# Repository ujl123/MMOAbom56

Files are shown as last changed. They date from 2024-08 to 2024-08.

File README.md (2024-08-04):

# MMOAbom56
WIP board for the MMOAbom56, a board ostensibly for playing mmo games.
The board technically works as-is, but build at your own risk and all that.

Followed the guide on https://flatfootfox.com/ergogen-introduction/ and was able to complete this in a few hours , well written guide with a lot of details.

If you do want to fab and print this ...  
The pcb files can be found in MMOAbom56/pcbs/gerber/.   
The stl files for is in MMOAbom56/case/  
The (vial) firmware can be found in firmware/compiled  

You will also need

1x rp2040 pro micro mcu (the firmware assumes rp2040, if not you will need to edit the pins to atmega pin names)  
2x male header sockets
2x female header sockets
7x flat m2 screw
7x m2 threaded inserts
56x chocv1 switches of your choice  
56x chocv1 keycaps  
56x chocv1 hotswap sockets  
56x 1N4148 smd diode (through hole) or 1N4148 SOD-123 (smd)
1x (optional) reset butto (find a small one as the gap between the case and pcb is very small.)

designed-a-keyboard-for-playing-mmo-games-wow-specifically-v0-pu3llmdz1ngd1

designed-a-keyboard-for-playing-mmo-games-wow-specifically-v0-29fuxel32ngd1

designed-a-keyboard-for-playing-mmo-games-wow-specifically-v0-pfk2x8a62ngd1

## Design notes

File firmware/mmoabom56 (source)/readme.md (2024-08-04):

# mmoabom56

mmoabom56

*A short description of the keyboard/project*

* Keyboard Maintainer: [ujl123](https://github.com/ujl123)
* Hardware Supported: *The PCBs, controllers supported*
* Hardware Availability: *Links to where you can find this hardware*

Make example for this keyboard (after setting up your build environment):

    make mmoabom56:default

Flashing example for this keyboard:

    make mmoabom56:default:flash

See the [build environment setup](https://docs.qmk.fm/#/getting_started_build_tools) and the [make instructions](https://docs.qmk.fm/#/getting_started_make_guide) for more information. Brand new to QMK? Start with our [Complete Newbs Guide](https://docs.qmk.fm/#/newbs).

## Bootloader

Enter the bootloader in 3 ways:

* **Bootmagic reset**: Hold down the key at (0,0) in the matrix (usually the top left key or Escape) and plug in the keyboard
* **Physical reset button**: Briefly press the button on the back of the PCB - some may have pads you must short instead
* **Keycode in layout**: Press the key mapped to `QK_BOOT` if it is available

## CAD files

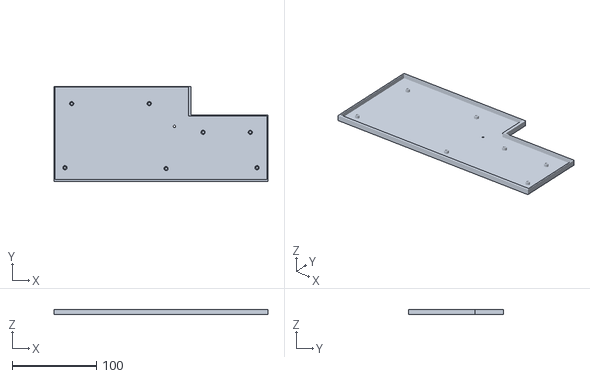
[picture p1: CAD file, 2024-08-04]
MMOAbom56/output/cases/printCase.stl
254.0 x 113.0 x 6.00

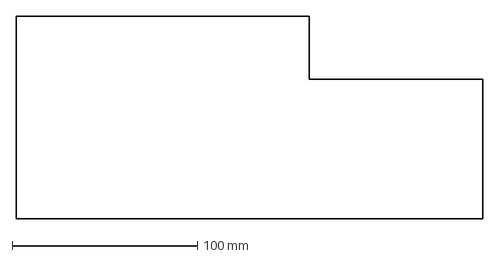
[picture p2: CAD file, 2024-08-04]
MMOAbom56/output/outlines/board.dxf
252.0 x 109.4 mm

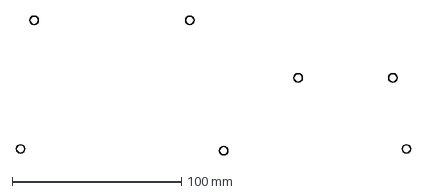
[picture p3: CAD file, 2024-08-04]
MMOAbom56/output/outlines/standoffs.dxf
233.0 x 82.0 mm

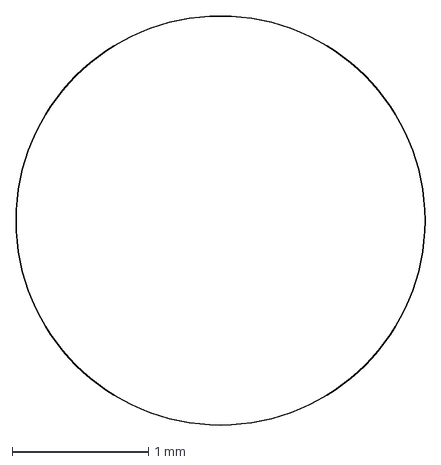
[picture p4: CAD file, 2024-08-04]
MMOAbom56/output/outlines/resetHole.dxf
3.00 x 3.00 mm

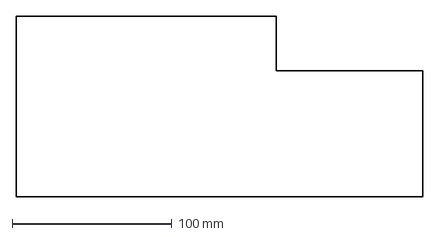
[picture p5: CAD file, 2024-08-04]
MMOAbom56/output/outlines/xlBoard.dxf
254.0 x 113.0 mm

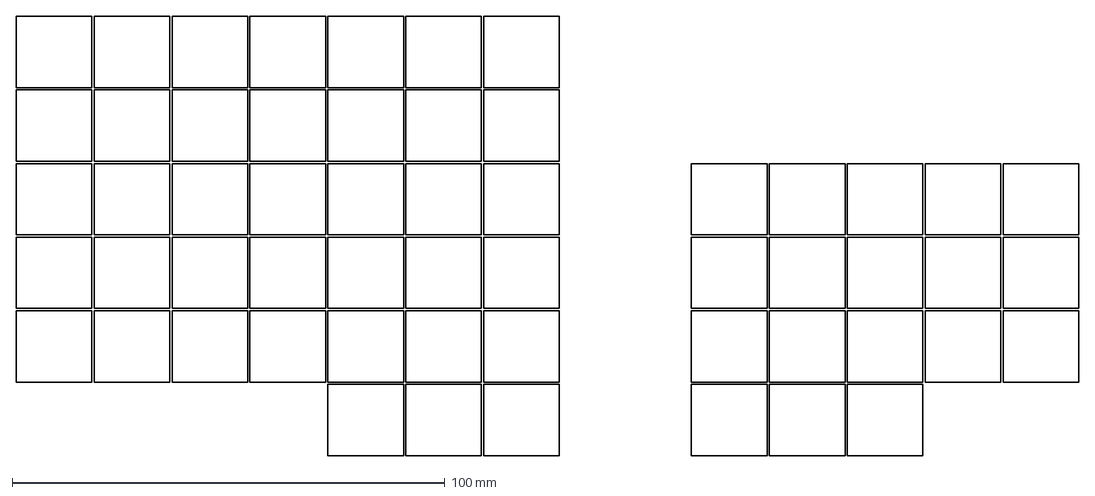
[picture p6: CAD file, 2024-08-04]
MMOAbom56/output/outlines/keys.dxf
245.5 x 101.5 mm

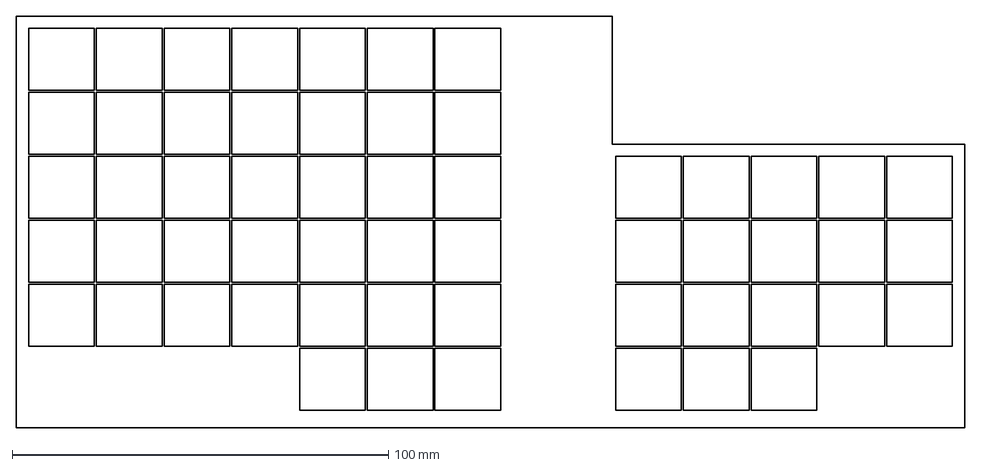
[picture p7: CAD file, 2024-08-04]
MMOAbom56/output/outlines/combo.dxf
252.0 x 109.4 mm

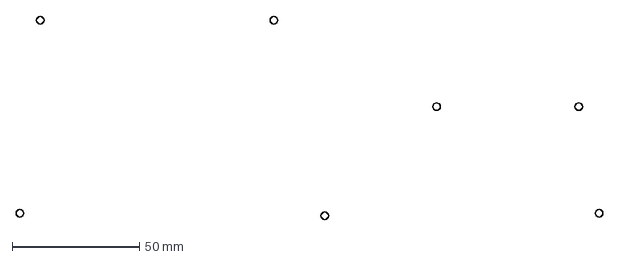
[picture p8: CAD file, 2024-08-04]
MMOAbom56/output/outlines/mounting.dxf
231.0 x 80.0 mm

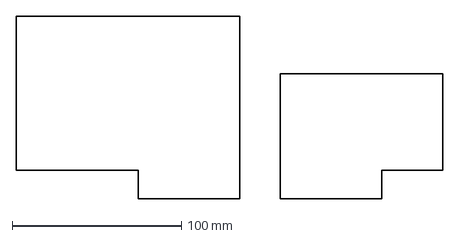
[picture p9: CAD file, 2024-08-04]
MMOAbom56/output/outlines/raw.dxf
252.0 x 108.0 mm

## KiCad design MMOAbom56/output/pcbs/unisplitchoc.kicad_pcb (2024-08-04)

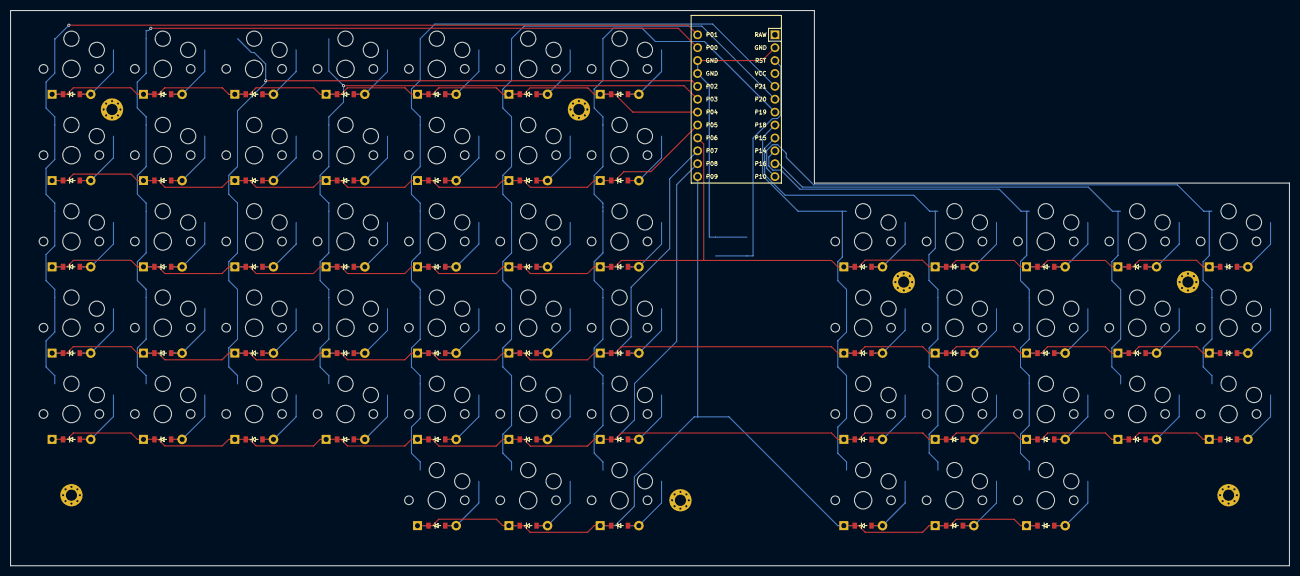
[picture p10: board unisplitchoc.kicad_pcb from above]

Board: 2 copper layers, 252.0 x 109.4 mm, 121 parts (0 on the bottom side), 76 nets.

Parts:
B1: SW_TACT_ALPS_SKQGABE010
D1, D2, D3, D4, D5, D6, D7, D8, D9, D10, D11, D12, D13, D14, D15, D16, D17, D18, D19, D20, D21, D22, D23, D24, D25, D26, D27, D28, D29, D30, D31, D32, D33, D34, D35, D36, D37, D38, D39, D40, D41, D42, D43, D44, D45, D46, D47, D48, D49, D50, D51, D52, D53, D54, D55, D56: ComboDiode
MCU1: ProMicro
S1, S2, S3, S4, S5, S6, S7, S8, S9, S10, S11, S12, S13, S14, S15, S16, S17, S18, S19, S20, S21, S22, S23, S24, S25, S26, S27, S28, S29, S30, S31, S32, S33, S34, S35, S36, S37, S38, S39, S40, S41, S42, S43, S44, S45, S46, S47, S48, S49, S50, S51, S52, S53, S54, S55, S56: PG1350
_1, _2, _3, _4, _5, _6, _7: MountingHole_2.2mm_M2_Pad_Via

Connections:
GND: B1.1, MCU1.2, MCU1.15, MCU1.16
P0: MCU1.14, S6.1, S7.1, S8.1, S9.1, S10.1
P1: MCU1.13, S1.1, S2.1, S3.1, S4.1, S5.1
P2: MCU1.17, S11.1, S12.1, S13.1, S14.1, S15.1
P3: MCU1.18, S16.1, S17.1, S18.1, S19.1, S20.1
P4: D5.1, D10.1, D15.1, D20.1, D26.1, D32.1, D38.1, MCU1.19
P5: D4.1, D9.1, D14.1, D19.1, D25.1, D31.1, D37.1, MCU1.20
P6: D3.1, D8.1, D13.1, D18.1, D24.1, D30.1, D36.1, D42.1, D46.1, D50.1, D53.1, D56.1, MCU1.21
P7: D2.1, D7.1, D12.1, D17.1, D23.1, D29.1, D35.1, D41.1, D45.1, D49.1, D52.1, D55.1, MCU1.22
P8: D1.1, D6.1, D11.1, D16.1, D22.1, D28.1, D34.1, D40.1, D44.1, D48.1, D51.1, D54.1, MCU1.23
P9: D21.1, D27.1, D33.1, D39.1, D43.1, D47.1, MCU1.24
P10: MCU1.12, S54.1, S55.1, S56.1
P14: MCU1.10, S47.1, S48.1, S49.1, S50.1
P15: MCU1.9, S43.1, S44.1, S45.1, S46.1
P16: MCU1.11, S51.1, S52.1, S53.1
P18: MCU1.8, S39.1, S40.1, S41.1, S42.1
P19: MCU1.7, S33.1, S34.1, S35.1, S36.1, S37.1, S38.1
P20: MCU1.6, S27.1, S28.1, S29.1, S30.1, S31.1, S32.1
P21: MCU1.5, S21.1, S22.1, S23.1, S24.1, S25.1, S26.1
RST: B1.2, MCU1.3
lindex_bottom: D28.2, S28.2
lindex_function: D32.2, S32.2
lindex_home: D29.2, S29.2
lindex_mod: D27.2, S27.2
lindex_num: D31.2, S31.2
lindex_top: D30.2, S30.2
linner_bottom: D34.2, S34.2
linner_function: D38.2, S38.2
linner_home: D35.2, S35.2
linner_mod: D33.2, S33.2
linner_num: D37.2, S37.2
linner_top: D36.2, S36.2
lmacro_bottom: D1.2, S1.2
lmacro_function: D5.2, S5.2
lmacro_home: D2.2, S2.2
lmacro_num: D4.2, S4.2
lmacro_top: D3.2, S3.2
lmiddle_bottom: D22.2, S22.2
lmiddle_function: D26.2, S26.2
lmiddle_home: D23.2, S23.2
lmiddle_mod: D21.2, S21.2
lmiddle_num: D25.2, S25.2
lmiddle_top: D24.2, S24.2
louter_bottom: D6.2, S6.2
louter_function: D10.2, S10.2
louter_home: D7.2, S7.2
louter_num: D9.2, S9.2
louter_top: D8.2, S8.2
lpinky_bottom: D11.2, S11.2
lpinky_function: D15.2, S15.2
lpinky_home: D12.2, S12.2
lpinky_num: D14.2, S14.2
lpinky_top: D13.2, S13.2
lring_bottom: D16.2, S16.2
lring_function: D20.2, S20.2
lring_home: D17.2, S17.2
lring_num: D19.2, S19.2
lring_top: D18.2, S18.2
rindex_bottom: D44.2, S44.2
rindex_home: D45.2, S45.2
rindex_mod: D43.2, S43.2
rindex_top: D46.2, S46.2
rinner_bottom: D40.2, S40.2
rinner_home: D41.2, S41.2
rinner_mod: D39.2, S39.2
rinner_top: D42.2, S42.2
rmiddle_bottom: D48.2, S48.2
rmiddle_home: D49.2, S49.2
rmiddle_mod: D47.2, S47.2
rmiddle_top: D50.2, S50.2
rpinky_bottom: D54.2, S54.2
rpinky_home: D55.2, S55.2
rpinky_top: D56.2, S56.2
rring_bottom: D51.2, S51.2
rring_home: D52.2, S52.2
rring_top: D53.2, S53.2

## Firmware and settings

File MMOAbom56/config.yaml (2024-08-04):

units:
  # Proxy Spacing Variables
  kx: cx
  ky: cy
  # Padding Variables
  px: kx + 6
  py: ky + 6
  # Double Padding Variables
  dpx: kx + 8
  dpy: ky + 8  
  screwSize: 1.5
  standoffSize: 2.5
points:
  zones:
    matrix:
      anchor:
        shift: [100, -200]    
      key:
        padding: 1ky
        spread: 1kx
      columns:
        lmacro:
          key.column_net: P1
          rows.mod.skip: true
        louter:
          key.column_net: P0
          rows.mod.skip: true
        lpinky:
          key.column_net: P2
          rows.mod.skip: true
        lring:
          key.column_net: P3
          rows.mod.skip: true
        lmiddle:
          key.column_net: P21
        lindex:
          key.column_net: P20
        linner:
          key.column_net: P19
        rinner:
          key.spread: 2px
          key.column_net: P18
          rows.function.skip: true
          rows.num.skip: true
        rindex:
          key.column_net: P15 
          rows.function.skip: true
          rows.num.skip: true
        rmiddle:
          key.column_net: P14
          rows.function.skip: true
          rows.num.skip: true
        rring:
          key.column_net: P16
          rows.function.skip: true
          rows.num.skip: true
          rows.mod.skip: true
        rpinky:
          key.column_net: P10
          rows.function.skip: true
          rows.num.skip: true
          rows.mod.skip: true
      rows:
        mod:
          row_net: P9
        bottom:
          row_net: P8
        home:
          row_net: P7
        top:
          row_net: P6
        num:
          row_net: P5
        function:
          row_net: P4
outlines:
  raw:
    - what: rectangle
      where: true
      size: [px, py]
  keys:
    - what: rectangle
      where: true
      size: [kx-0.5,ky-0.5]
  board:
    - what: polygon
      operation: stack
      points:
        - ref: matrix_lmacro_function
          shift: [-0.5px,0.5py]
        - ref: matrix_linner_function
          shift: [1.6px,0.5py]
        - ref: matrix_linner_top
          shift: [1.6px,0.5py]          
        - ref: matrix_rpinky_top
          shift: [0.5px,0.5py]          
        - ref: matrix_rpinky_bottom
          shift: [0.5px,-1.3py]
        - ref: matrix_lmacro_bottom
          shift: [-0.5px,-1.3py]
  xlBoard:
    - what: polygon
      operation: stack
      points:
        - ref: matrix_lmacro_function
          shift: [-0.5dpx,0.5dpy]
        - ref: matrix_linner_function
          shift: [1.6dpx,0.5dpy]
        - ref: matrix_linner_top
          shift: [1.6dpx,0.5dpy]          
        - ref: matrix_rpinky_top
          shift: [0.5dpx,0.5dpy]          
        - ref: matrix_rpinky_bottom
          shift: [0.5dpx,-1.3dpy]
        - ref: matrix_lmacro_bottom
          shift: [-0.5dpx,-1.3dpy]
  combo:
    - name: board
    - operation: subtract
      name: keys
  mounting:
    - what: circle
      radius: screwSize
      where:
        ref: [matrix_lmacro_function]
        shift: [8,-8]
    - what: circle
      radius: screwSize
      where:
        ref: [matrix_linner_function]
        shift: [-8,-8]
    - what: circle
      radius: screwSize
      where:
        ref: [matrix_rinner_top]
        shift: [8,-8]
    - what: circle
      radius: screwSize
      where:
        ref: [matrix_rpinky_top]
        shift: [-8,-8]
    - what: circle
      radius: screwSize
      where:
        ref: [matrix_lmacro_bottom]
        shift: [0,-16]
    - what: circle
      radius: screwSize
      where:
        ref: [matrix_linner_mod]
        shift: [12,0]      
    - what: circle
      radius: screwSize
      where:
        ref: [matrix_rpinky_bottom]
        shift: [0,-16]
  standoffs:
    - what: circle
      radius: standoffSize
      where:
        ref: [matrix_lmacro_function]
        shift: [8,-8]
    - what: circle
      radius: standoffSize
      where:
        ref: [matrix_linner_function]
        shift: [-8,-8]
    - what: circle
      radius: standoffSize
      where:
        ref: [matrix_rinner_top]
        shift: [8,-8]
    - what: circle
      radius: standoffSize
      where:
        ref: [matrix_rpinky_top]
        shift: [-8,-8]
    - what: circle
      radius: standoffSize
      where:
        ref: [matrix_lmacro_bottom]
        shift: [0,-16]
    - what: circle
      radius: standoffSize
      where:
        ref: [matrix_linner_mod]
        shift: [12,0]      
    - what: circle
      radius: standoffSize
      where:
        ref: [matrix_rpinky_bottom]
        shift: [0,-16]
  resetHole:
    - what: circle
      radius: screwSize
      where:
        ref: matrix_linner_function
        shift: [22,-35]
pcbs:
  unisplitchoc:
    template: kicad8
    outlines:
      main:
        outline: board
    footprints:
      choc_hotswap:
        what: choc
        where: true
        params:
          keycaps: true
          reverse: false
          hotswap: true
          from: "{{column_net}}"
          to: "{{colrow}}"
      diode:
        what: diode
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

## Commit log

2024-08-04 Add files via upload
    Ergogen configs and outputs for MMOAbom56
    [board.dxf, combo.dxf, keys.dxf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]
2024-08-04 gerber files for pcb fabs
    gerber files for pcb fabs, zip these up and upload into your pcb fab of choice
    [unisplitchoc-B_Cu.gbr, unisplitchoc-B_Mask.gbr, unisplitchoc-B_Paste.gbr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]
